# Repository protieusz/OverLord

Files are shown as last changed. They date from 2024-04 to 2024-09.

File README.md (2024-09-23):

# OverLord

Lotus layout unified split with 2x mcus & 2x trackballs.

# Sponsorship

Thank you PCBWay for sponsoring. For all you PCB/PCBA needs, PCBWay is the way to go. Good quality and customer service. During files submission, PCBWay take the time to check the BOM file and the component placement file to make sure that it is up to specs. If there are any issues, PCBWay will email back and inform the customer if there are any corrections that need to be made and also provide solutions for the customer. I highly recommend PCBWay. 

# Featured On KBDNews
https://kbd.news/OverLord-2477.html

# Detailed Summary

OverLord is a heavily modified version of Noraneko42L which has been blessed by darakuneko himself for the mod. Noraneko42L was originally designed by [darakuneko](https://github.com/darakuneko/Noraneko/tree/main/noraneko42l).

Entire PCB was designed using EasyEDA. ~I will upload a convert PCB file later.~ Be warn, the conversion might not be accurate and you might see a lot of DRC errors in KiCad but in EasyEDA it is ok since I have a working PCB right now.

~Right now at the moment still working out the kinks of getting the 2nd trackball to scroll and the orientation for the main mouse trackball. All the keys are working properly.~

A List Of Mods Made To The Original PCB file by darakuneko:

-Eliminate the extra 6th columns on each sides.

-Two circular holes were created in the middle that can accomodate 2x 25mm trackballs powered by 2x PMW3360 sensors.

-Base of the trackball holders with lens cut out is integrated into the top case with integrated 5mm switch plate. Top case sits flush with pcb.

-Full keyboard case was created to house the PCB.

-OverLord is powered by 2x RP2040 Core - As which you can get from AE.

-Shout out to miketronic from Fingerpunch discord for helping me with the QMK coding from his [BR/KN](https://github.com/miketronic/brkn-keyboard) and modifing the matrix to fit my OverLord. No suppport will be given since I just copy and paste.

-Shout to Doesntfazer of KeyboardDweebs.net for proofing reading and sanity checking my PCB schematic.

-Special thanks to Doesntfazer for fixing my QMK pointing device settings and finally got the scrolling ball to work.

-Use M2 brass hot inserts 3.2mm diameter and 4mm length for the M2 screws to secure the case. I forgot how long is my M2 screws are but they should be greater than 10mm so estimated around 14.6mm. Play around with and buy multiple M2 lenght screws.

-"Eye of Sauron" icon logo embross on the top case was borrowed from [Symbolon from the Noun Project](https://thenounproject.com/icon/eye-of-sauron-1007756/). "Eye of Sauron" logo was used to give it a dark lord theme.

-Both RP2040 Core-A mcus will be "linked" together by header pin wires instead of TRRS connector.

-Heads up if you are using Resin STEP files, resin print did not come out good, since the middle part was warped and the factory recommend to use 3.5mm for the bottom flat case area in order to prevent warping during print. Just use the PLA is more safer. Use the files at your own risk. You can modify the STEP files.

# Production Pics












# Test Fitting



C9845A4F-E4CC-4C1D-95F6-BF27D2E29501
case02

# Renders

Screenshot 2024-08-18 at 1 39 52 AM
Screenshot 2024-08-18 at 1 40 03 AM
Screenshot 2024-08-01 at 8 59 47 PM
Screenshot 2024-08-01 at 8 59 58 PM
Screenshot 2024-08-02 at 10 06 23 AM
Screenshot 2024-08-02 at 10 06 38 AM
Screenshot 2024-08-15 at 10 27 16 PM
Screenshot 2024-08-15 at 10 27 04 PM
Screenshot 2024-08-15 at 10 26 42 PM
Screenshot 2024-08-15 at 10 26 24 PM
Screenshot 2024-08-13 at 10 55 25 PM
Screenshot 2024-08-13 at 10 55 19 PM
Screenshot 2024-08-13 at 10 55 12 PM
Screenshot 2024-08-12 at 10 28 48 PM
Screenshot 2024-08-15 at 10 27 32 PM
Screenshot 2024-08-15 at 10 28 31 PM

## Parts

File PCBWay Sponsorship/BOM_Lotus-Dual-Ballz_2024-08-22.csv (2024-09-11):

ID | Name | Designator | Footprint | Quantity | Manufacturer Part | Manufacturer | Supplier | Supplier Part | Price | link
1 | Header pins 1x04 1MM HOLES | H1,H5 | 1X04 2.54MM HOLES HEADERS PINS 1MM HOLES | 2 |  |  |  |  | [DNP不要贴];
2 | PMW3360DM-T2QU | U7,U7B | PMW3360DM-T2QU.PACK | 2 | PMW3360DM-T2QU |  |  |  | [DNP不要贴]; | http://www.pixart.com/upload/PMS0058-PMW3360DM-T2QU-NNDS-R1.30-06042016_20160902201411.pdf
3 | 4.7uF | C17,C19,C20,C17B,C19B,C20B | C0402 | 6 | CL05A475MP5NRNC | SAMSUNG(三星) | LCSC | C23733 | 0.005 | https://lcsc.com/eda_search?q=C23733&%26type=1&ref=editor
4 | 100nF | C18,C18B | C0402 | 2 | CL05B104KB54PNC | SAMSUNG(三星) | LCSC | C307331 | 0.005 | https://lcsc.com/eda_search?q=C307331&%26type=1&ref=editor
5 | PRTR5V0U2X,215 | D11,D5 | SOT-143_L2.9-W1.3-P1.92-LS2.3-BR | 2 | PRTR5V0U2X,215 | Nexperia(安世) | LCSC | C12333 | 0.092 | https://item.szlcsc.com/280548.html
6 | BSMD0805-020-15V | F1,F2 | F0805 | 2 | BSMD0805-020-15V | BHFUSE(佰宏) | LCSC | C883103 | 0.045 | https://item.szlcsc.com/343298.html
7 | 5.1kΩ | R1,R2,R3,R4 | R0402 | 4 | 0402WGF5101TCE | UNI-ROYAL(厚声) | LCSC | C25905 | 0.001 | https://item.szlcsc.com/323315.html
8 | 10kΩ | R10,R12,R13,R10B,R12B,R13B | R0402 | 6 | 0402WGF1002TCE | UNI-ROYAL(厚声) | LCSC | C25744 | 0.001 | https://lcsc.com/eda_search?q=C25744&%26type=1&ref=editor
9 | 39Ω | R11,R11B | R0402 | 2 | 0402WGJ0390TCE | UNI-ROYAL(厚声) | LCSC | C25164 |  | https://lcsc.com/eda_search?q=C25164&%26type=1&ref=editor
10 | 15kΩ | R14,R14B | R0402 | 2 | 0402WGF1502TCE | UNI-ROYAL(厚声) | LCSC | C25756 | 0.001 | https://lcsc.com/eda_search?q=C25756&%26type=1&ref=editor
11 | RP2040-Core-A | U1,U1B | RP2040-CORE-A | 2 |  |  |  |  | [DNP不要贴];
12 | TYPE-C-31-M-12 | USBC1,USBC2 | USB-C_SMD-TYPE-C-31-M-12 | 2 | TYPE-C-31-M-12 | 韩国韩荣 | LCSC | C165948 | 0.161 | https://so.szlcsc.com/global.html?c=&k=C165948
13 | AP2127K-ADJTRG1 | U8B,U8 | SOT-23-5_L3.0-W1.7-P0.95-LS2.8-BR | 2 | AP2127K-ADJTRG1 | DIODES(美台) | LCSC | C96343 | 0.074 | https://lcsc.com/eda_search?q=C96343&%26type=1&ref=editor
14 | SM4007PL | D000,D000B,D001,D001B,D002,D002B,D003,D003B,D004,D004B,D100,D100B,D101,D101B,D102,D102B,D103,D103B,D104,D104B,D200,D200B,D201,D201B,D202,D202B,D203,D203B,D204,D204B,D302,D302B,D303,D303B,D304,D304B | SOD-123F_L2.8-W1.8-LS3.7-RD | 36 | SM4007PL | MDD | LCSC | C64898 | 0.006 | https://item.szlcsc.com/60254.html
15 | Switch | K000,K000B,K001,K001B,K002,K002B,K003,K003B,K004,K004B,K100,K100B,K101,K101B,K102,K102B,K103,K103B,K104,K104B,K200,K200B,K201,K201B,K202,K202B,K203,K203B,K204,K204B,K302,K302B,K303,K303B,K304,K304B | CHERRY_MX_100_MILLMAX | 36 |  |  |  |  | [DNP不要贴];

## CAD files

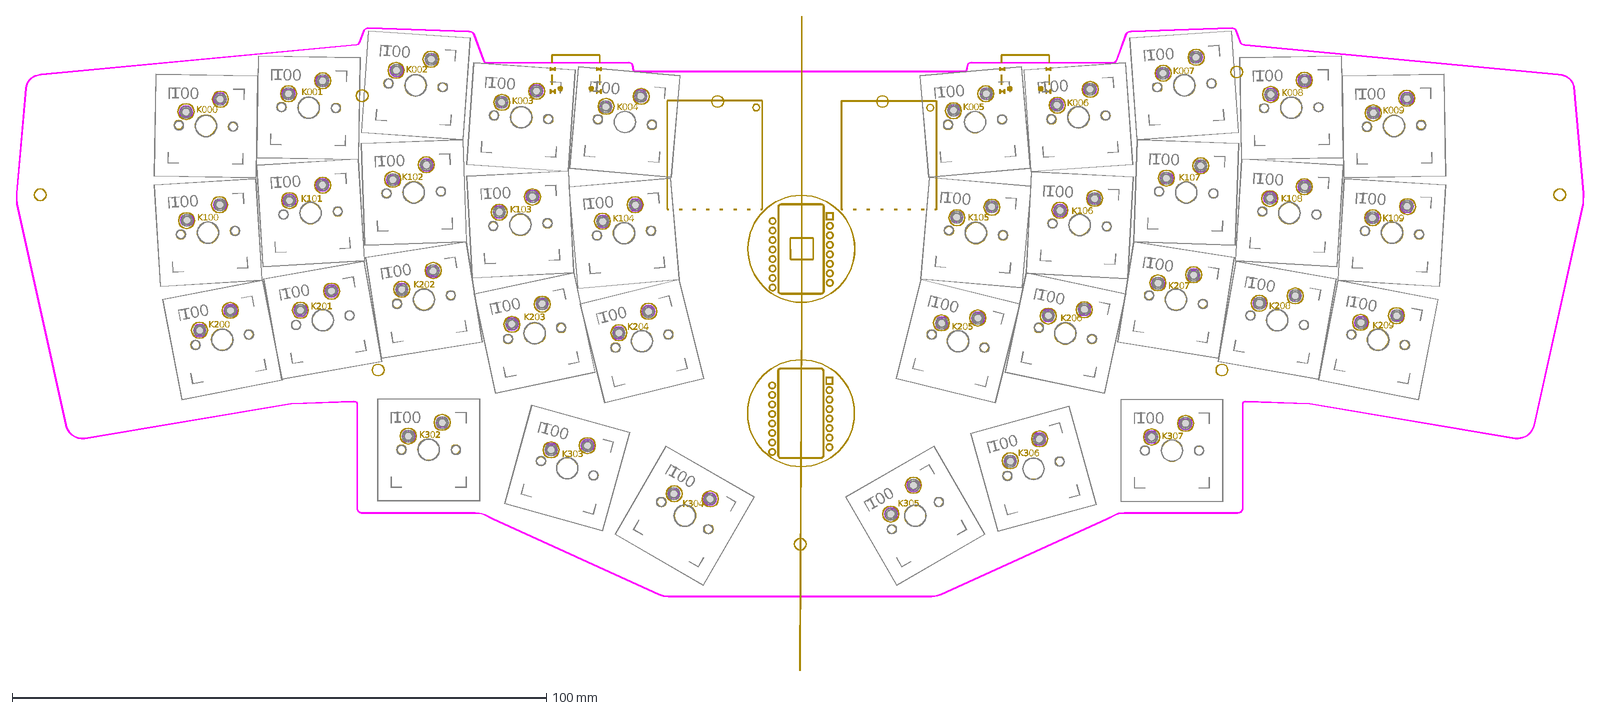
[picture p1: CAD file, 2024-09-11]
PCB_Lotus-Dual-Ballz_2024-07-25.dxf
K000
100
K001
K002
K003
K004
K005
K006
K007
K008
K009
K100
K101
K102
K103
K104
K105
K106
K107
K108
K109
K200
K201
K202
K203
K204
K205
K206
K207
K208
K209
K302
K303
K304
K305
K306
K307

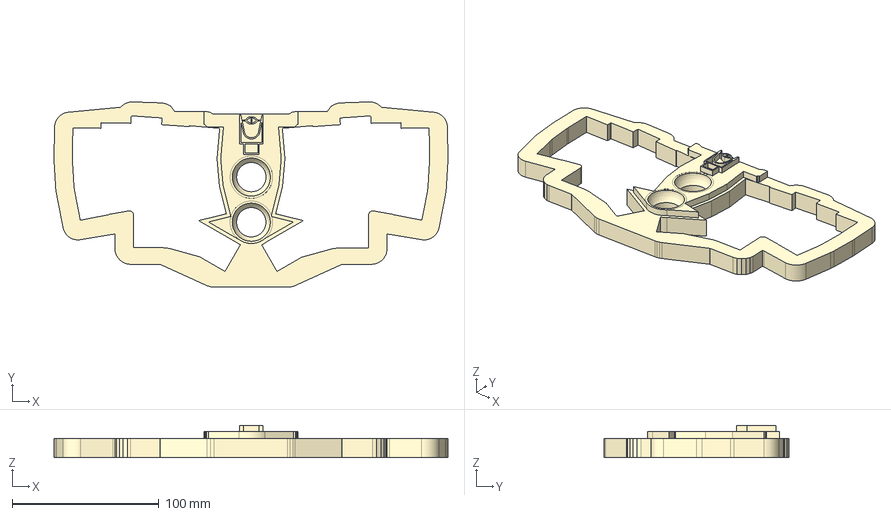
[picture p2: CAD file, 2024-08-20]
STEPS/OverLord Lotus Layout 2balls Top Virgin.step
268.7 x 126.4 x 22.0 mm

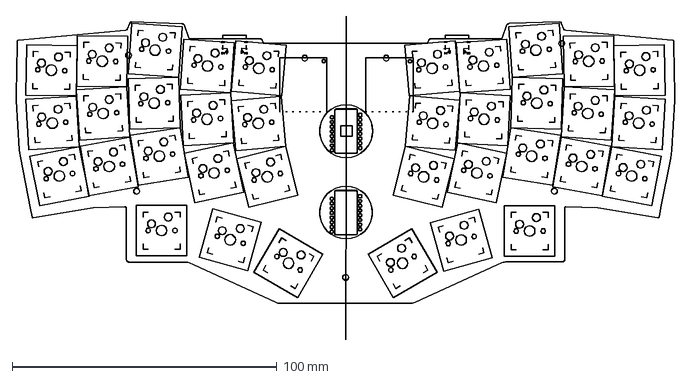
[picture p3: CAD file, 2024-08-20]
LotusBallsdual Final PCB.dxf
248.7 x 122.4 mm

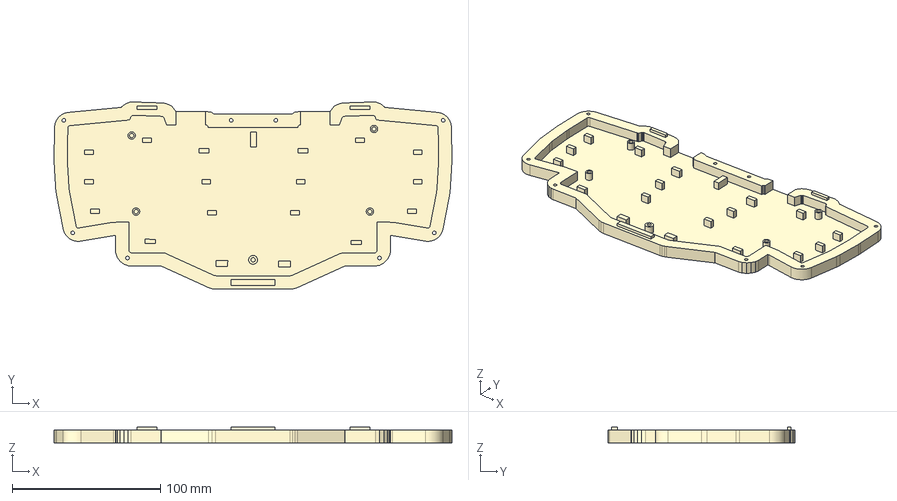
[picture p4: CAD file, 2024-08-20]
STEPS/OverLord Lotus Layout 2balls Bottom Resin.step
268.7 x 126.4 x 10.6 mm

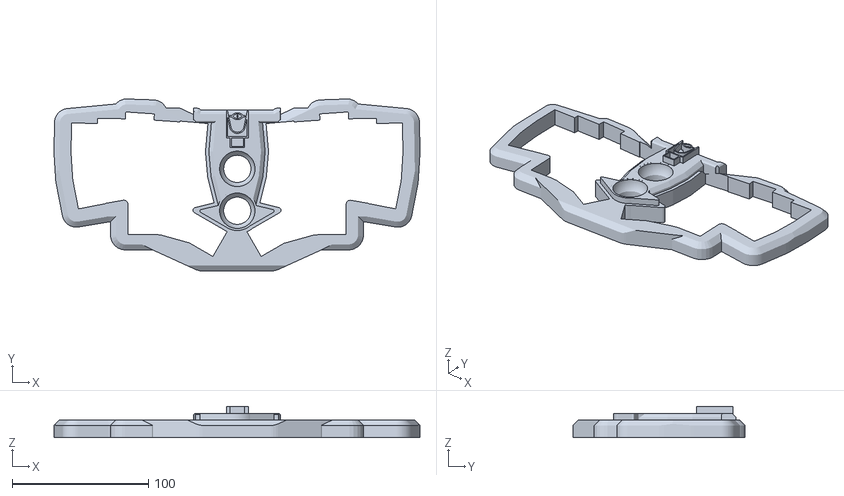
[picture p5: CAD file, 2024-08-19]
OverLordTop Case.stl
268.7 x 126.4 x 23.0

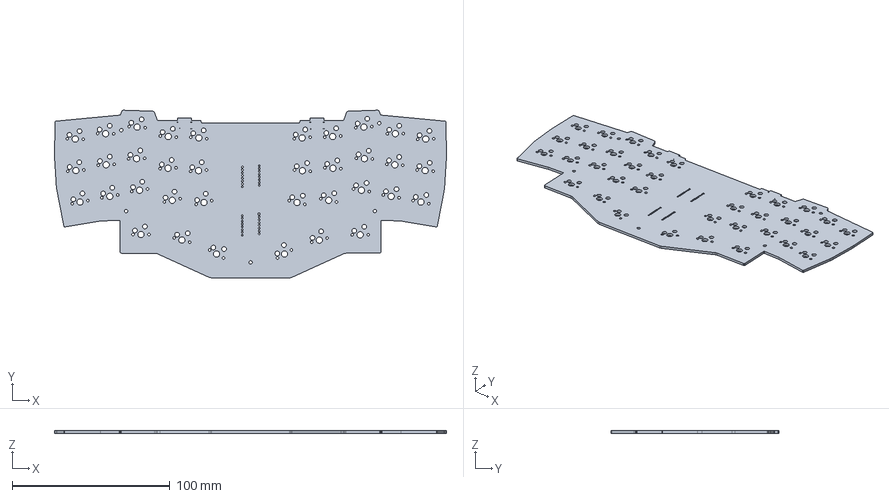
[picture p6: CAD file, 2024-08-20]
STEPS/OverLord Lotus Layout 2balls PCB mock.step
248.7 x 106.4 x 1.60 mm

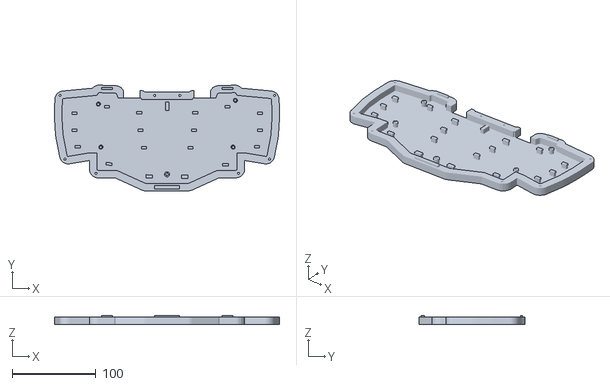
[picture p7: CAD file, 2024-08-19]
OverLord Bottom Holes.stl
268.7 x 126.4 x 10.6

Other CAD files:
STEPS/OverLord Lotus Layout 2balls Bottom Virgin.step
OverLord Bottom Resin.stl
STEPS/OverLord Lotus Layout 2balls Top PLA.step
OverLord PCB.stl
STEPS/OverLord Lotus Layout 2balls bottom PLA.step

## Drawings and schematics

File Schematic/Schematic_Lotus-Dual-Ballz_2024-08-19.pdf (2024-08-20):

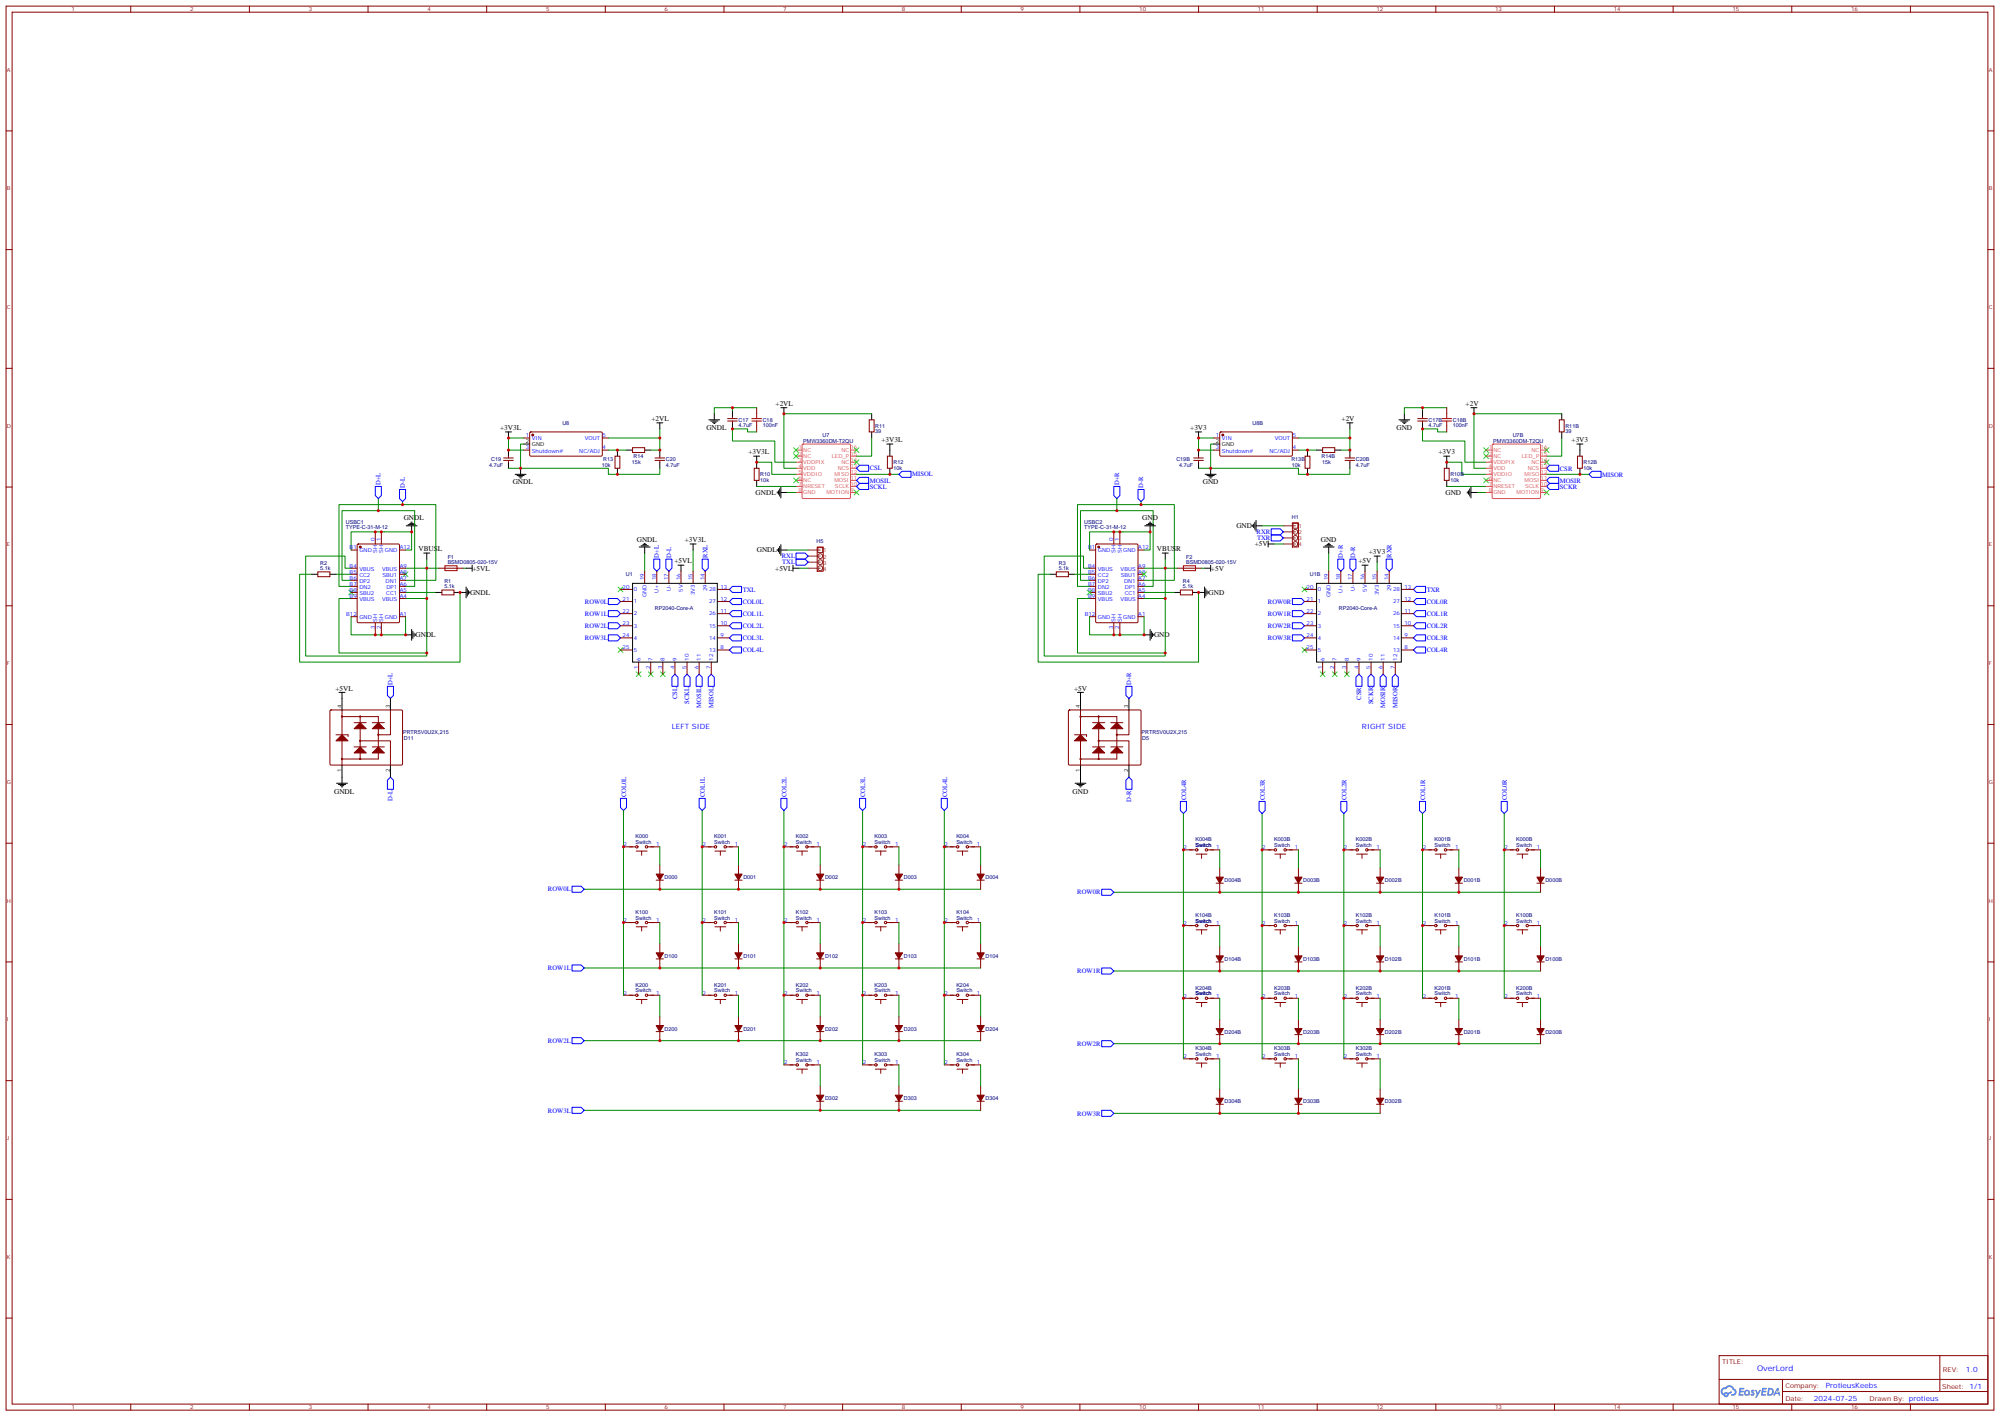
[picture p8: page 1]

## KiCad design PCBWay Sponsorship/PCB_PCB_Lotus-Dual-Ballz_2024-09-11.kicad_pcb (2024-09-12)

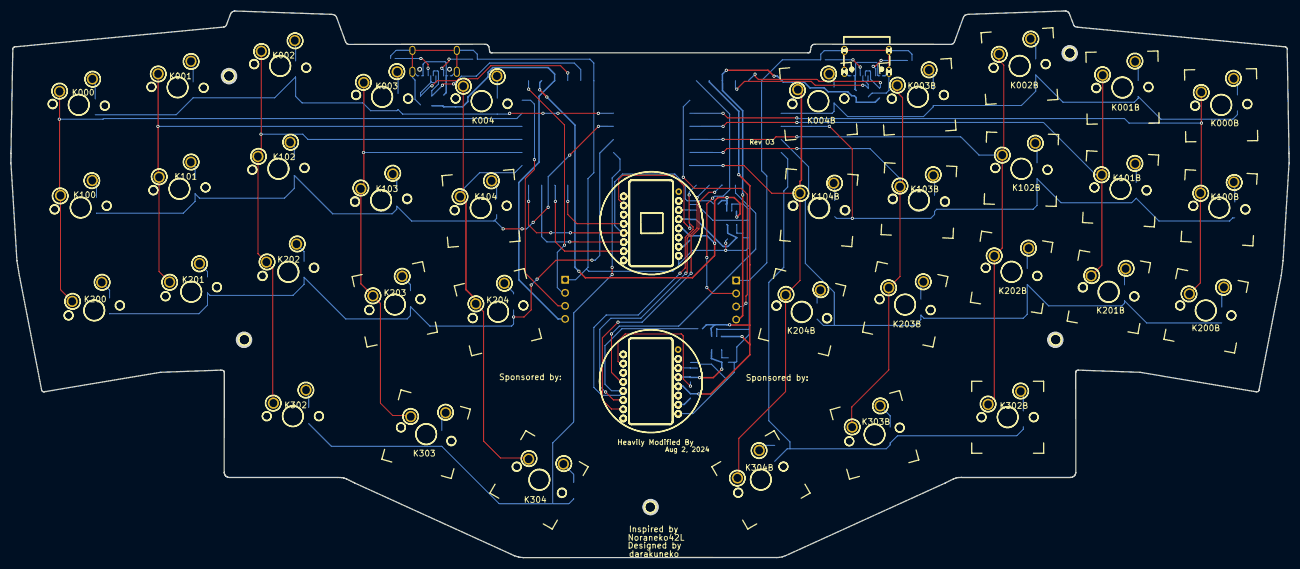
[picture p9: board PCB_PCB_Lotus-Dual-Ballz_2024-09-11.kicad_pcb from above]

Board: 2 copper layers, 248.7 x 106.4 mm, 108 parts (0 on the bottom side), 92 nets.

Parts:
C17, C17B, C19, C19B, C20, C20B: 4.7uF; C0402
C18, C18B: 100nF; C0402
D000, D000B, D001, D001B, D002, D002B, D003, D003B, D004, D004B, D100, D100B, D101, D101B, D102, D102B, D103, D103B, D104, D104B, D200, D200B, D201, D201B, D202, D202B, D203, D203B, D204, D204B, D302, D302B, D303, D303B, D304, D304B: SM4007PL; SOD-123F_L2.8-W1.8-LS3.7-RD
D5, D11: PRTR5V0U2X,215; SOT-143_L2.9-W1.3-P1.92-LS2.3-BR
F1, F2: BSMD0805-020-15V; F0805
H1, H5: Header pins 1x04 1MM HOLES; 1X04 2.54MM HOLES HEADERS PINS 1MM HOLES
K000, K000B, K001, K001B, K002, K002B, K003, K003B, K004, K004B, K100, K100B, K101, K101B, K102, K102B, K103, K103B, K104, K104B, K200, K200B, K201, K201B, K202, K202B, K203, K203B, K204, K204B, K302, K302B, K303, K303B, K304, K304B: Switch; CHERRY_MX_100_MILLMAX
R1, R2, R3, R4: 5.1kΩ; R0402
R10, R10B, R12, R12B, R13, R13B: 10kΩ; R0402
R11, R11B: 39Ω; R0402
R14, R14B: 15kΩ; R0402
U1, U1B: RP2040-Core-A; RP2040-CORE-A
U7, U7B: PMW3360DM-T2QU; PMW3360DM-T2QU.PACK
U8, U8B: AP2127K-ADJTRG1; SOT-23-5_L3.0-W1.7-P0.95-LS2.8-BR
USBC1, USBC2: TYPE-C-31-M-12; USB-C_SMD-TYPE-C-31-M-12

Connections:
+2V: C20B.2, R11B.2, R14B.2, U7B.4, U8B.5
+2VL: C20.2, R11.2, R14.2, U7.4, U8.5
+3V3: C19B.2, R10B.2, R12B.2, U1B.15, U7B.5, U8B.1, U8B.3
+3V3L: C19.2, R10.2, R12.2, U1.15, U7.5, U8.1, U8.3
+5V: D5.4, F2.2, H1.4, U1B.16
+5VL: D11.4, F1.2, H5.4, U1.16
C18B_1: C17B.1, C18B.1, U7B.3
COL0L: K000.2, K100.2, K200.2, U1.12
COL0R: K000B.2, K100B.2, K200B.2, U1B.12
COL1L: K001.2, K101.2, K201.2, U1.11
COL1R: K001B.2, K101B.2, K201B.2, U1B.11
COL2L: K002.2, K102.2, K202.2, K302.2, U1.10
COL2R: K002B.2, K102B.2, K202B.2, K302B.2, U1B.10
COL3L: K003.2, K103.2, K203.2, K303.2, U1.9
COL3R: K003B.2, K103B.2, K203B.2, K303B.2, U1B.9
COL4L: K004.2, K104.2, K204.2, K304.2, U1.8
COL4R: K004B.2, K104B.2, K204B.2, K304B.2, U1B.8
CSL: U1.4, U7.13
CSR: U1B.4, U7B.13
D000B_2: D000B.2, K000B.1
D000_2: D000.2, K000.1
D001B_2: D001B.2, K001B.1
D001_2: D001.2, K001.1
D002B_2: D002B.2, K002B.1
D002_2: D002.2, K002.1
D003B_2: D003B.2, K003B.1
D003_2: D003.2, K003.1
D004B_2: D004B.2, K004B.1
D004_2: D004.2, K004.1
D100_2: D100.2, K100.1
D101B_2: D101B.2, K101B.1
D101_2: D101.2, K101.1
D102B_2: D102B.2, K102B.1
D102_2: D102.2, K102.1
D103B_2: D103B.2, K103B.1
D103_2: D103.2, K103.1
D104B_2: D104B.2, K104B.1
D104_2: D104.2, K104.1
D200B_2: D200B.2, K200B.1
D200_2: D200.2, K200.1
D201B_2: D201B.2, K201B.1
D201_2: D201.2, K201.1
D202B_2: D202B.2, K202B.1
D202_2: D202.2, K202.1
D203B_2: D203B.2, K203B.1
D203_2: D203.2, K203.1
D204B_2: D204B.2, K204B.1
D204_2: D204.2, K204.1
D302B_2: D302B.2, K302B.1
D302_2: D302.2, K302.1
D303B_2: D303B.2, K303B.1
D303_2: D303.2, K303.1
D304_2: D304.2, K304.1
D+L: D11.3, U1.18, USBC1.A6, USBC1.B6
D+R: D5.3, U1B.18, USBC2.A6, USBC2.B6
D-L: D11.2, U1.17, USBC1.A7, USBC1.B7
D-R: D5.2, U1B.17, USBC2.A7, USBC2.B7
GND: C17B.2, C18B.2, C19B.1, C20B.1, D5.1, H1.1, R3.1, R4.2, R13B.1, U1B.19, U7B.8, U8B.2, USBC2.0, USBC2.1, USBC2.2, USBC2.3, USBC2.A1, USBC2.A12, USBC2.B1, USBC2.B12
GNDL: C17.2, C18.2, C19.1, C20.1, D11.1, H5.1, R1.2, R2.1, R13.1, U1.19, U7.8, U8.2, USBC1.0, USBC1.1, USBC1.2, USBC1.3, USBC1.A1, USBC1.A12, USBC1.B1, USBC1.B12
K100B_1: D100B.2, K100B.1
K304B_1: D304B.2, K304B.1
MISOL: R12.1, U1.7, U7.12
MISOR: R12B.1, U1B.7, U7B.12
MOSIL: U1.6, U7.11
MOSIR: U1B.6, U7B.11
R1_1: R1.1, USBC1.A5
R2_2: R2.2, USBC1.B5
R10B_1: R10B.1, U7B.7
R11B_1: R11B.1, U7B.15
R14B_1: R13B.2, R14B.1, U8B.4
ROW0L: D000.1, D001.1, D002.1, D003.1, D004.1, U1.21
ROW0R: D000B.1, D001B.1, D002B.1, D003B.1, D004B.1, U1B.21
ROW1L: D100.1, D101.1, D102.1, D103.1, D104.1, U1.22
ROW1R: D100B.1, D101B.1, D102B.1, D103B.1, D104B.1, U1B.22
ROW2L: D200.1, D201.1, D202.1, D203.1, D204.1, U1.23
ROW2R: D200B.1, D201B.1, D202B.1, D203B.1, D204B.1, U1B.23
ROW3L: D302.1, D303.1, D304.1, U1.24
ROW3R: D302B.1, D303B.1, D304B.1, U1B.24
RXL: H5.2, U1.14
RXR: H1.2, U1B.14
SCKL: U1.5, U7.10
SCKR: U1B.5, U7B.10
TXL: H5.3, U1.13
TXR: H1.3, U1B.13
U7_3: C17.1, C18.1, U7.3
U7_7: R10.1, U7.7
U7_15: R11.1, U7.15
U8_4: R13.2, R14.1, U8.4
USBC2_A5: R4.1, USBC2.A5
USBC2_B5: R3.2, USBC2.B5
VBUSL: F1.1, USBC1.A4, USBC1.A9, USBC1.B4, USBC1.B9
VBUSR: F2.1, USBC2.A4, USBC2.A9, USBC2.B4, USBC2.B9

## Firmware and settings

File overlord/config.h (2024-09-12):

// Copyright 2024 
// ProtieusKeebs
// SPDX-License-Identifier: GPL-2.0+

#pragma once

#define RP2040_BOOTLOADER_DOUBLE_TAP_RESET // Activates the double-tap behavior
#define RP2040_BOOTLOADER_DOUBLE_TAP_RESET_TIMEOUT 200U // Timeout window in ms in which the double tap can occur.

#ifdef COMBO_ENABLE
#    define COMBO_COUNT 3
#    define COMBO_TERM 150
#endif


#    define SPLIT_USB_DETECT
#    define USE_SERIAL
#    define SERIAL_USART_FULL_DUPLEX
#    define SERIAL_USART_TX_PIN GP28
#    define SERIAL_USART_RX_PIN GP29
#    define SERIAL_USART_PIN_SWAP
#    define MASTER_LEFT

// SPI
#    define SPI_DRIVER SPID1
#    define SPLIT_POINTING_ENABLE
#    define POINTING_DEVICE_CS_PIN GP9
#    define SPI_SCK_PIN GP10
#    define SPI_MISO_PIN GP12
#    define SPI_MOSI_PIN GP11

// PMW3360 settings
//#    define PMW3360_CPI 12000
//#    define PMW3360_CS_DIVISOR 8
//#    define POINTING_DEVICE_TASK_THROTTLE_MS 10
//#    define POINTING_DEVICE_ROTATION_180_RIGHT
#    define POINTING_DEVICE_INVERT_X_RIGHT
#    define POINTING_DEVICE_COMBINED //Do not put pointing_device_right in any area of the config.h or else your scrolling ball will not work! Credit: Doesntfazer
//#      define POINTING_DEVICE_ROTATION_180_RIGHT
//#      define POINTING_DEVICE_INVERT_X

///#    define POINTING_DEVICE_INVERT_Y
//#    define ROTATIONAL_TRANSFORM_ANGLE 97
//#    define MOUSE_EXTENDED_REPORT


// Mouse key speed and acceleration.
#    undef MOUSEKEY_DELAY
#    define MOUSEKEY_DELAY          0
#    undef MOUSEKEY_INTERVAL
#    define MOUSEKEY_INTERVAL       16
#    undef MOUSEKEY_WHEEL_DELAY
#    define MOUSEKEY_WHEEL_DELAY    0
#    undef MOUSEKEY_MAX_SPEED
#    define MOUSEKEY_MAX_SPEED      6
#    undef MOUSEKEY_TIME_TO_MAX
#    define MOUSEKEY_TIME_TO_MAX    64

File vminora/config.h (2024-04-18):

/*
Copyright 2023 Sadek Baroudi <sadekbaroudi@gmail.com>

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
You should have received a copy of the GNU General Public License
along with this program.  If not, see <http://www.gnu.org/licenses/>.
*/

#pragma once

/* key matrix size */
// Rows are doubled-up
#define MATRIX_ROWS 8
#define MATRIX_COLS 10

// wiring of each half
#define MATRIX_ROW_PINS { GP11, GP10, GP9, GP8 }
#define MATRIX_COL_PINS { GP28, GP27, GP26, GP15, GP14 }

// VIK pin config
#define VIK_SPI_DRIVER    SPID0
#define VIK_SPI_SCK_PIN   GP6
#define VIK_SPI_MOSI_PIN  GP7
#define VIK_SPI_MISO_PIN  GP4
#define VIK_SPI_CS        GP5
#define VIK_I2C_DRIVER    I2CD1
#define VIK_I2C_SDA_PIN   GP2
#define VIK_I2C_SCL_PIN   GP3
#define VIK_GPIO_1        GP13
#define VIK_GPIO_2        GP29
#define VIK_WS2812_DI_PIN GP0

// Split config
#define SERIAL_PIO_USE_PIO1
#define SERIAL_USART_TX_PIN GP1     // USART TX pin

#define WS2812_DI_PIN GP0

#ifdef VIK_TRACKBALL_ENABLE
    #define POINTING_DEVICE_LEFT
#endif

//#include "keyboards/fingerpunch/src/config_post.h"

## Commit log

2024-08-20 Case STEP files
    [OverLord Lotus Layout 2balls Bottom Resin.step, OverLord Lotus Layout 2balls Bottom Virgin.step, OverLord Lotus Layout 2balls PCB mock.step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]
2024-08-20 DXF layout
    [LotusBallsdual Final PCB.dxf]
2024-09-12 Convert pcb file from EasyEda json file
    [PCB_PCB_Lotus-Dual-Ballz_2024-09-11.kicad_pcb]

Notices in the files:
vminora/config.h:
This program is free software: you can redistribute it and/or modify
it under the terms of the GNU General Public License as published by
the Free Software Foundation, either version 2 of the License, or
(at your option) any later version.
